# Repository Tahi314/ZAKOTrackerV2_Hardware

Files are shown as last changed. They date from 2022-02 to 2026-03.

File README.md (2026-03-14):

# ZAKOTrackerV2 - Hardware

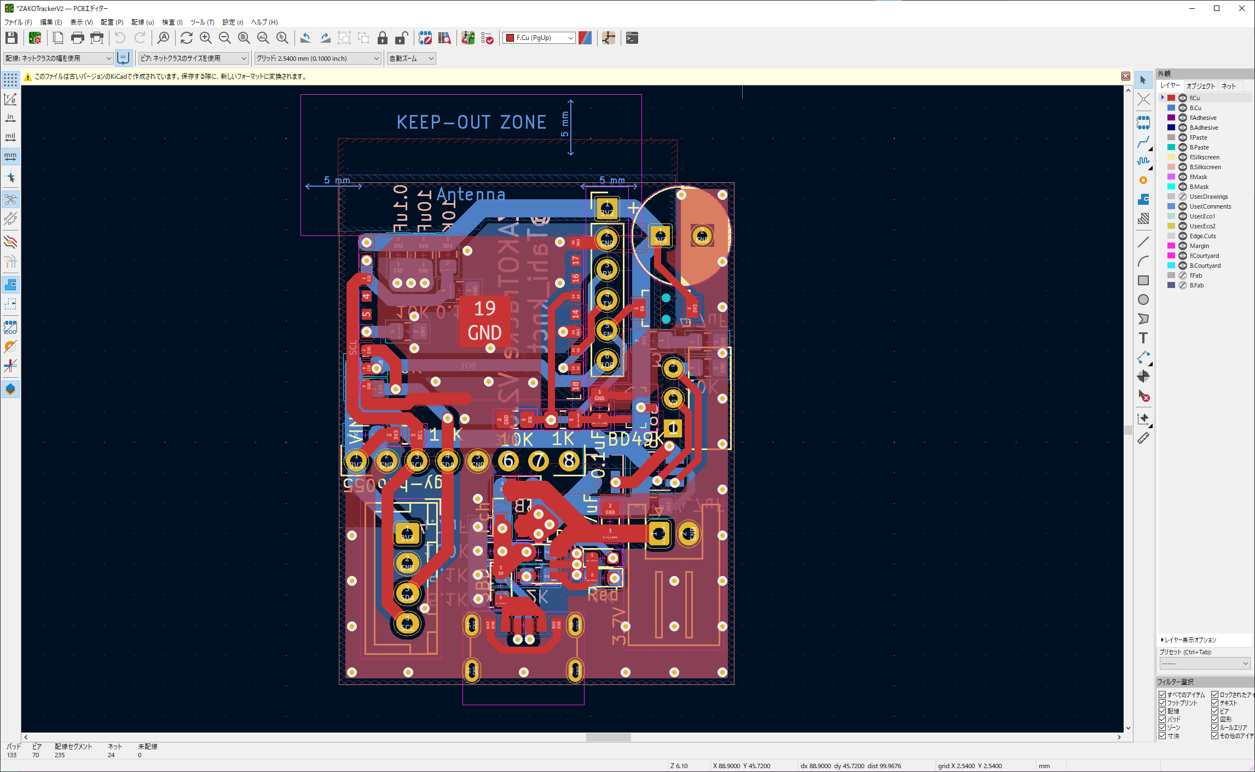
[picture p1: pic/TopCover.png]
TopCover


自作VRモーショントラッカー「ZAKOTracker」V2の基板設計データ。

BNO055 IMUの値をESP-NOWで送信するセンサーノード基板です。

## 関連リポジトリ

- [ZAKOTrackerV2_ESP8266](https://github.com/Tahi314/ZAKOTrackerV2_ESP8266) - 送信側ファームウェア（ESP8266）
- [ZAKOTrackerV2_ESP32](https://github.com/Tahi314/ZAKOTrackerV2_ESP32) - 受信側ファームウェア（ESP32）

## 設計環境

- KiCad 6.0

## ディレクトリ構成

- `kicad/` - KiCad プロジェクトファイル
- `3d/` - 3Dモデル
- `pic/` - 画像

## 参考

- [ZAKOTrackerV1.0の解説記事（Zenn）](https://zenn.dev/tahi_314/articles/8bd749271e5c29)

## 著者

- [X](https://x.com/Tahi_314_main)
- [GitHub](https://github.com/Tahi314)

## ライセンス

<br />この作品は<a rel="license" href="http://creativecommons.org/licenses/by-nc/4.0/">クリエイティブ・コモンズ 表示 - 非営利 4.0 国際 ライセンス</a>の下に提供されています。

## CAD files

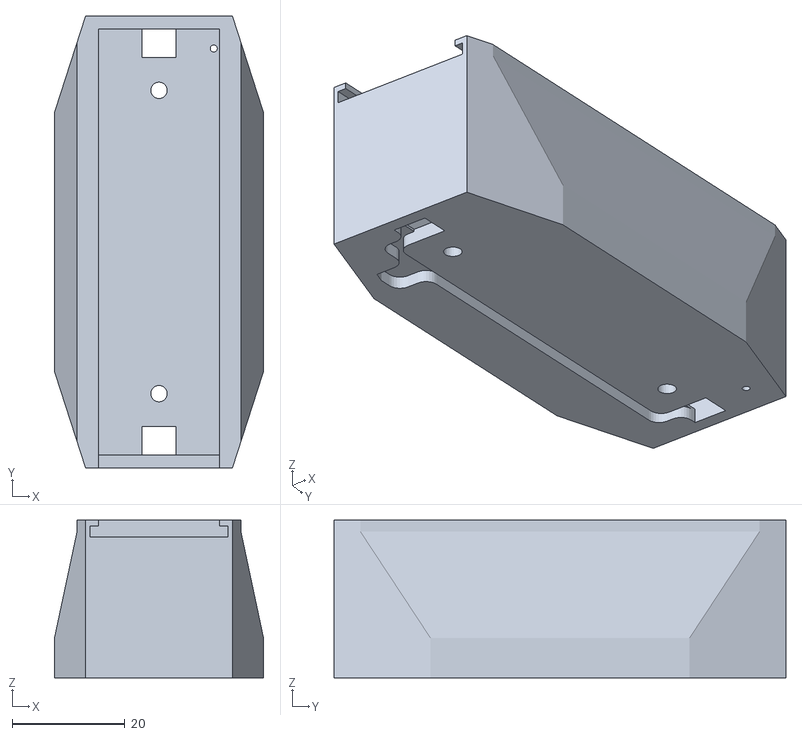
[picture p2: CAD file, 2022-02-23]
3d/3D_Part1.stl
37.0 x 80.0 x 27.9

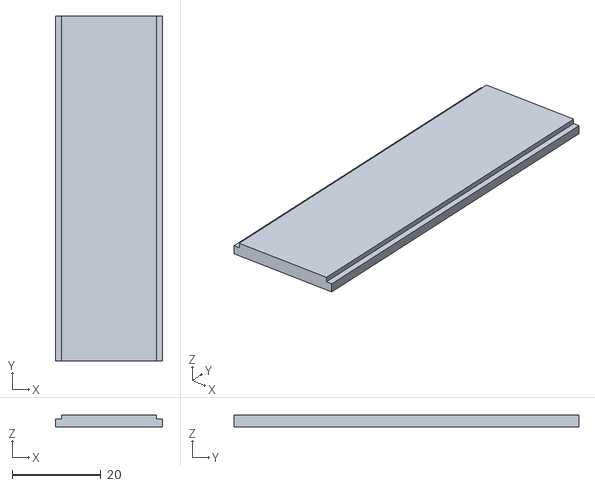
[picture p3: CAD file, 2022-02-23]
3d/3D_Part4.stl
24.0 x 77.7 x 2.80

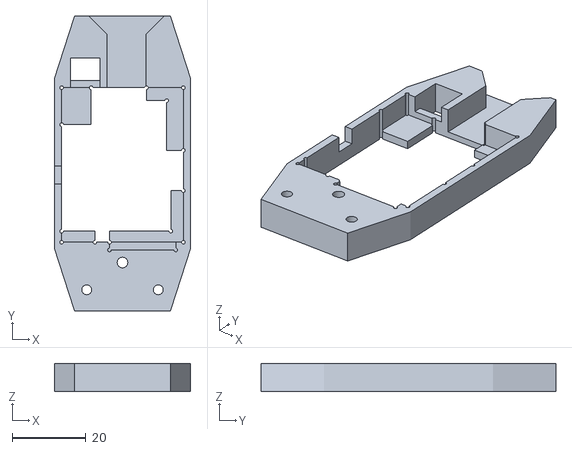
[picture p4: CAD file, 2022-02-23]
3d/3D_Part2.stl
37.0 x 80.0 x 7.60

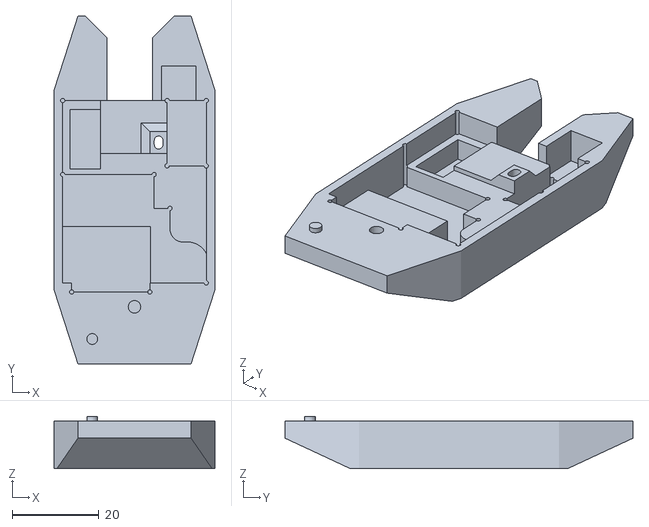
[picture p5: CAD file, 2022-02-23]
3d/3D_Part3.stl
37.0 x 80.0 x 12.0

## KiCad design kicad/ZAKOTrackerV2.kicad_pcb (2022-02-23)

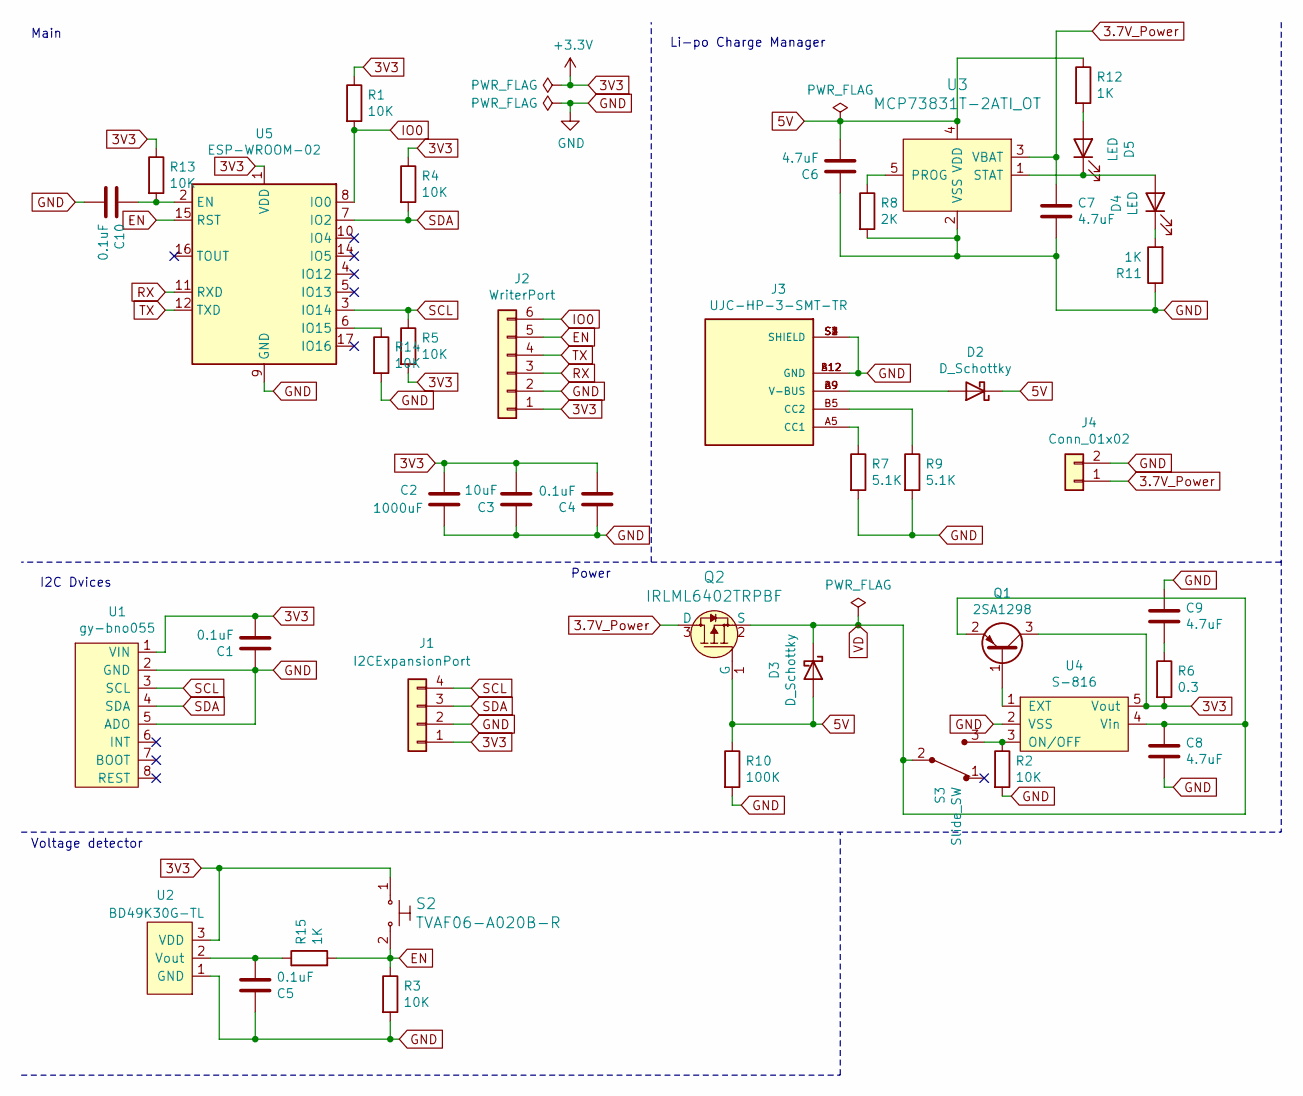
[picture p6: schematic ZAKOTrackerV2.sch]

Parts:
C1, C4, C5, C10: 0.1uF; C_0805_2012Metric_Pad1.18x1.45mm_HandSolder
C2: 1000uF; CP_Radial_D8.0mm_P3.50mm
C3: 10uF; C_0805_2012Metric_Pad1.18x1.45mm_HandSolder
C6, C7, C8, C9: 4.7uF; C_0805_2012Metric_Pad1.18x1.45mm_HandSolder
D2, D3: D_Schottky; D_SOD-323_HandSoldering
D4, D5: LED; D_0603_1608Metric_Pad1.05x0.95mm_HandSolder
J1: I2CExpansionPort; JST_XH_B4B-XH-A_1x04_P2.50mm_Vertical
J2: WriterPort; PinHeader_1x06_P2.54mm_Vertical
J3: UJC-HP-3-SMT-TR; CUI_UJC-HP-3-SMT-TR; PARTREV 1.0
J4: Conn_01x02; JST_XH_S2B-XH-A_1x02_P2.50mm_Horizontal
Q1: 2SA1298; SOT-23_Handsoldering
Q2: IRLML6402TRPBF; SOT-23_Handsoldering; MPN IRLML6402TRPBF; Digi-Key_PN IRLML6402PBFCT-ND
R1, R2, R3, R4, R5, R13, R14: 10K; R_0805_2012Metric_Pad1.20x1.40mm_HandSolder
R6: 0.3; R_0805_2012Metric_Pad1.20x1.40mm_HandSolder
R7, R9: 5.1K; R_0805_2012Metric_Pad1.20x1.40mm_HandSolder
R8: 2K; R_0805_2012Metric_Pad1.20x1.40mm_HandSolder
R10: 100K; R_0805_2012Metric_Pad1.20x1.40mm_HandSolder
R11, R12, R15: 1K; R_0805_2012Metric_Pad1.20x1.40mm_HandSolder
S2: TVAF06-A020B-R; MPN B3U-1000P; Digi-Key_PN SW1020CT-ND
S3: Slide_SW; SS-12D01G3; MPN EG1218; Digi-Key_PN EG1903-ND
U1: gy-bno055; gy-bno055-s
U2: BD49K30G-TL; SOT-23-3
U3: MCP73831T-2ATI_OT; SOT-23-5_HandSoldering; MPN MCP73831T-2ATI/OT; Digi-Key_PN MCP73831T-2ATI/OTCT-ND
U4: S-816; SOT-23-5_HandSoldering
U5: ESP-WROOM-02

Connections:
3.7V_Power: C7.1, J4.1, Q2.3 (D), U3.3 (VBAT)
3V3: C1.2, C2.1, C3.2, C4.2, J1.1, J2.1, Q1.3 (C), R1.1, R4.1, R5.2, R6.2, R13.1, S2.1, U1.1 (VIN), U2.3 (VDD), U4.5 (Vout), U5.1 (VDD)
5V: C6.2, D2.1 (K), D3.2 (A), Q2.1 (G), R10.1, R12.1, U3.4 (VDD)
EN: J2.5, R3.1, R15.2, S2.2, U5.15 (RST)
GND: C1.1, C2.2, C3.1, C4.1, C5.1, C6.1, C7.2, C8.2, C9.1, C10.2, J1.2, J2.2, J3.A12 (GND), J3.B12 (GND), J3.S1 (SHIELD), J3.S2 (SHIELD), J3.S3 (SHIELD), J3.S4 (SHIELD), J4.2, R2.2, R3.2, R7.2, R8.2, R9.2, R10.2, R11.1, R14.2, U1.2 (GND), U1.5 (ADO), U2.1 (GND), U3.2 (VSS), U4.2 (VSS), U5.9 (GND), U5.13 (GND), U5.18 (GND), U5.19 (GND)
IO0: J2.6, R1.2, U5.8 (IO0)
unnamed: C5.2, R15.1, U2.2 (Vout)
unnamed: C9.2, R6.1
unnamed: C10.1, R13.2, U5.2 (EN)
unnamed: D2.2 (A), J3.A9 (V-BUS), J3.B9 (V-BUS)
unnamed: D4.1 (K), R11.2
unnamed: D4.2 (A), D5.1 (K), U3.1 (STAT)
unnamed: D5.2 (A), R12.2
unnamed: J3.A5 (CC1), R7.1
unnamed: J3.B5 (CC2), R9.1
unnamed: Q1.1 (B), U4.1 (EXT)
unnamed: R2.1, S3.3, U4.3 (ON/OFF)
unnamed: R8.1, U3.5 (PROG)
unnamed: R14.1, U5.6 (IO15)
RX: J2.3, U5.11 (RXD)
SCL: J1.4, R5.1, U1.3 (SCL), U5.3 (IO14)
SDA: J1.3, R4.2, U1.4 (SDA), U5.7 (IO2)
TX: J2.4, U5.12 (TXD)
VD: C8.1, D3.1 (K), Q1.2 (E), Q2.2 (S), S3.2, U4.4 (Vin)

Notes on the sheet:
I2C Dvices
Main
Power
Voltage detector
Li-po Charge Manager

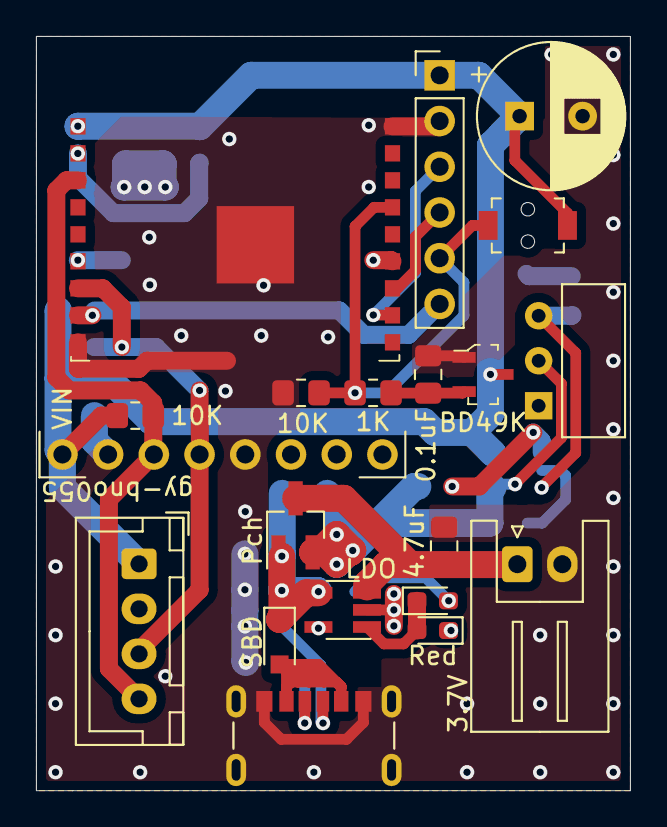
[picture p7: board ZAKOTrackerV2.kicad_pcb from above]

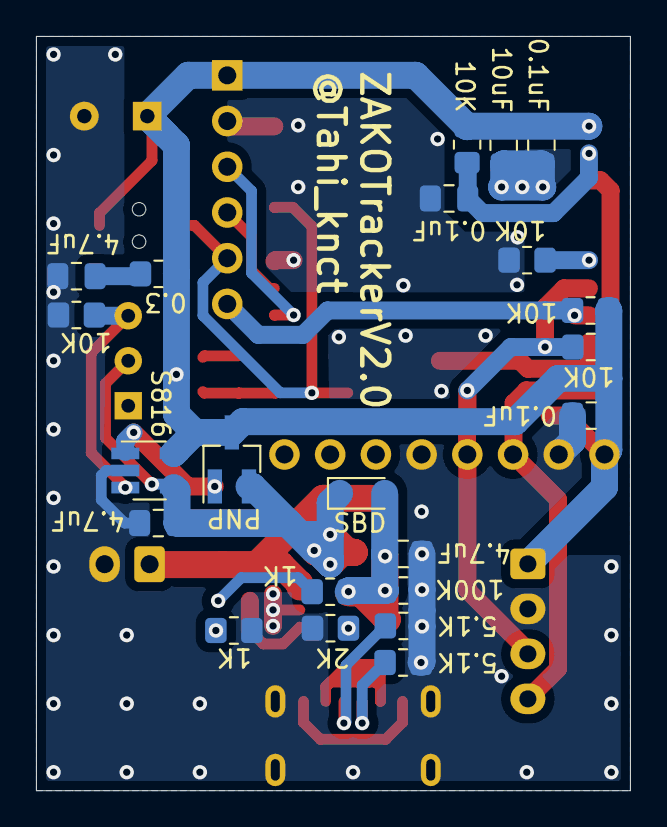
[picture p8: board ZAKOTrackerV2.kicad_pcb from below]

Board: 2 copper layers, 33.0 x 41.9 mm, 42 parts (22 on the bottom side), 24 nets.

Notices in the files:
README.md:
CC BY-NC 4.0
